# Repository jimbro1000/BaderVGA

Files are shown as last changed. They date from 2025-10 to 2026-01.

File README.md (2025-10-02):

# Terrible VGA #

Inspired by Ben Eater's discrete logic VGA and Leoneq's "bad vga" design,
this project implements a very basic, text only VGA display using just 1 
bit of a 128KB EEPROM data bus and 2KB of SRAM.

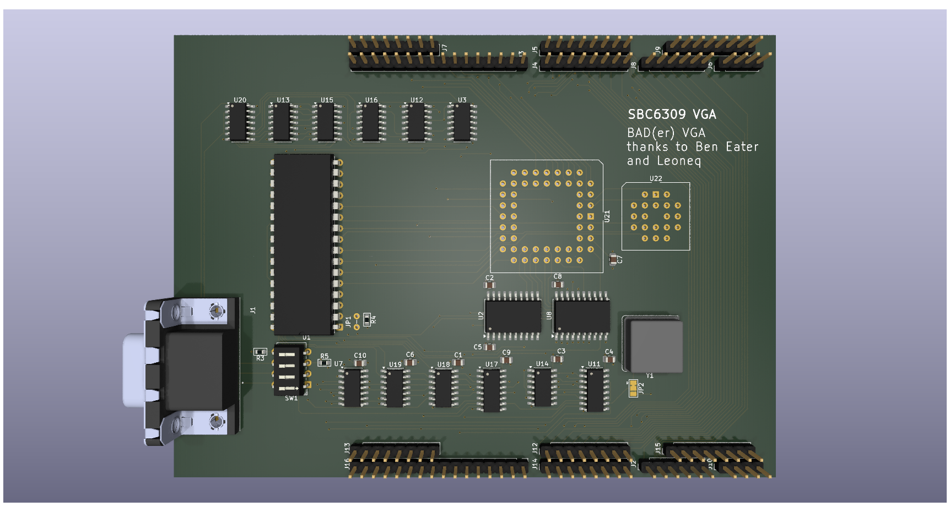
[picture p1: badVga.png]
Render of PCB


## Predictable issues ##

The logic chips used are clocked to near their limit (notably the 12-bit
counters) and struggle to meet the timing requirements of the design. 
Careful selection of components should help to resolve this.

The original designs by Ben and Leoneq were built on breadboard with no
practical ground plane and very little decoupling. This design is a 
dedicated 4-layer PCB with two solid ground planes that should help to 
resolve the problem. As much as possible, all signals are routed on a 
single layer with the "spare" layer used for power delivery.

Timing is not just an issue for the board's clock it is also a problem
for the host. The board clock is decoupled from the host which will,
inevitably, result in read and write conflicts. The host is expected to
be running at 3.147MHz while the video board is running at 20MHz. It
should be viable to gate host r/w operations such that they are blocked
(in the semaphore sense) by the video. If not the only option is to 
restrict write operations to the vertical blank period. The alternative
is to switch to a dual-port arrangement and bypass the problem completely.

## Integration ##
### Inputs ###

Integration with the host requires address bus, data bus, enable/select
and R/!W.

### Outputs ###

Outputs from the board, by default, are just the data bus but this needs
to be extended to include horizontal and vertical sync (TODO)

## Next ##

* Investigate dual-port ram option
* Investigate switch to 25.175MHz for better VGA compliance (can be
driven entirely from the host clock)
* Use latch and 3 bit load counter to reduce contention on databus
* Combine counter with 8 bit shift register (to reduce eeprom size
**and** allow eeprom programming on TL866 without adapters)
* Investigate combining with eeprom based state machine to manage
sync and blank timing

## References ##

Ben Eater VGA <https://eater.net/vga>

Leoneq <https://github.com/Leoneq/iNapGPU>

Dr Matt Regan VGA 
<https://github.com/Turing6502/ZX-Spectrum-No-ULA/blob/main/ZX%20Spectrum%20No%20ULA.pdf>

## License ##

This project is licensed under CC BY-SA 4.0
<https://creativecommons.org/licenses/by-sa/4.0/>

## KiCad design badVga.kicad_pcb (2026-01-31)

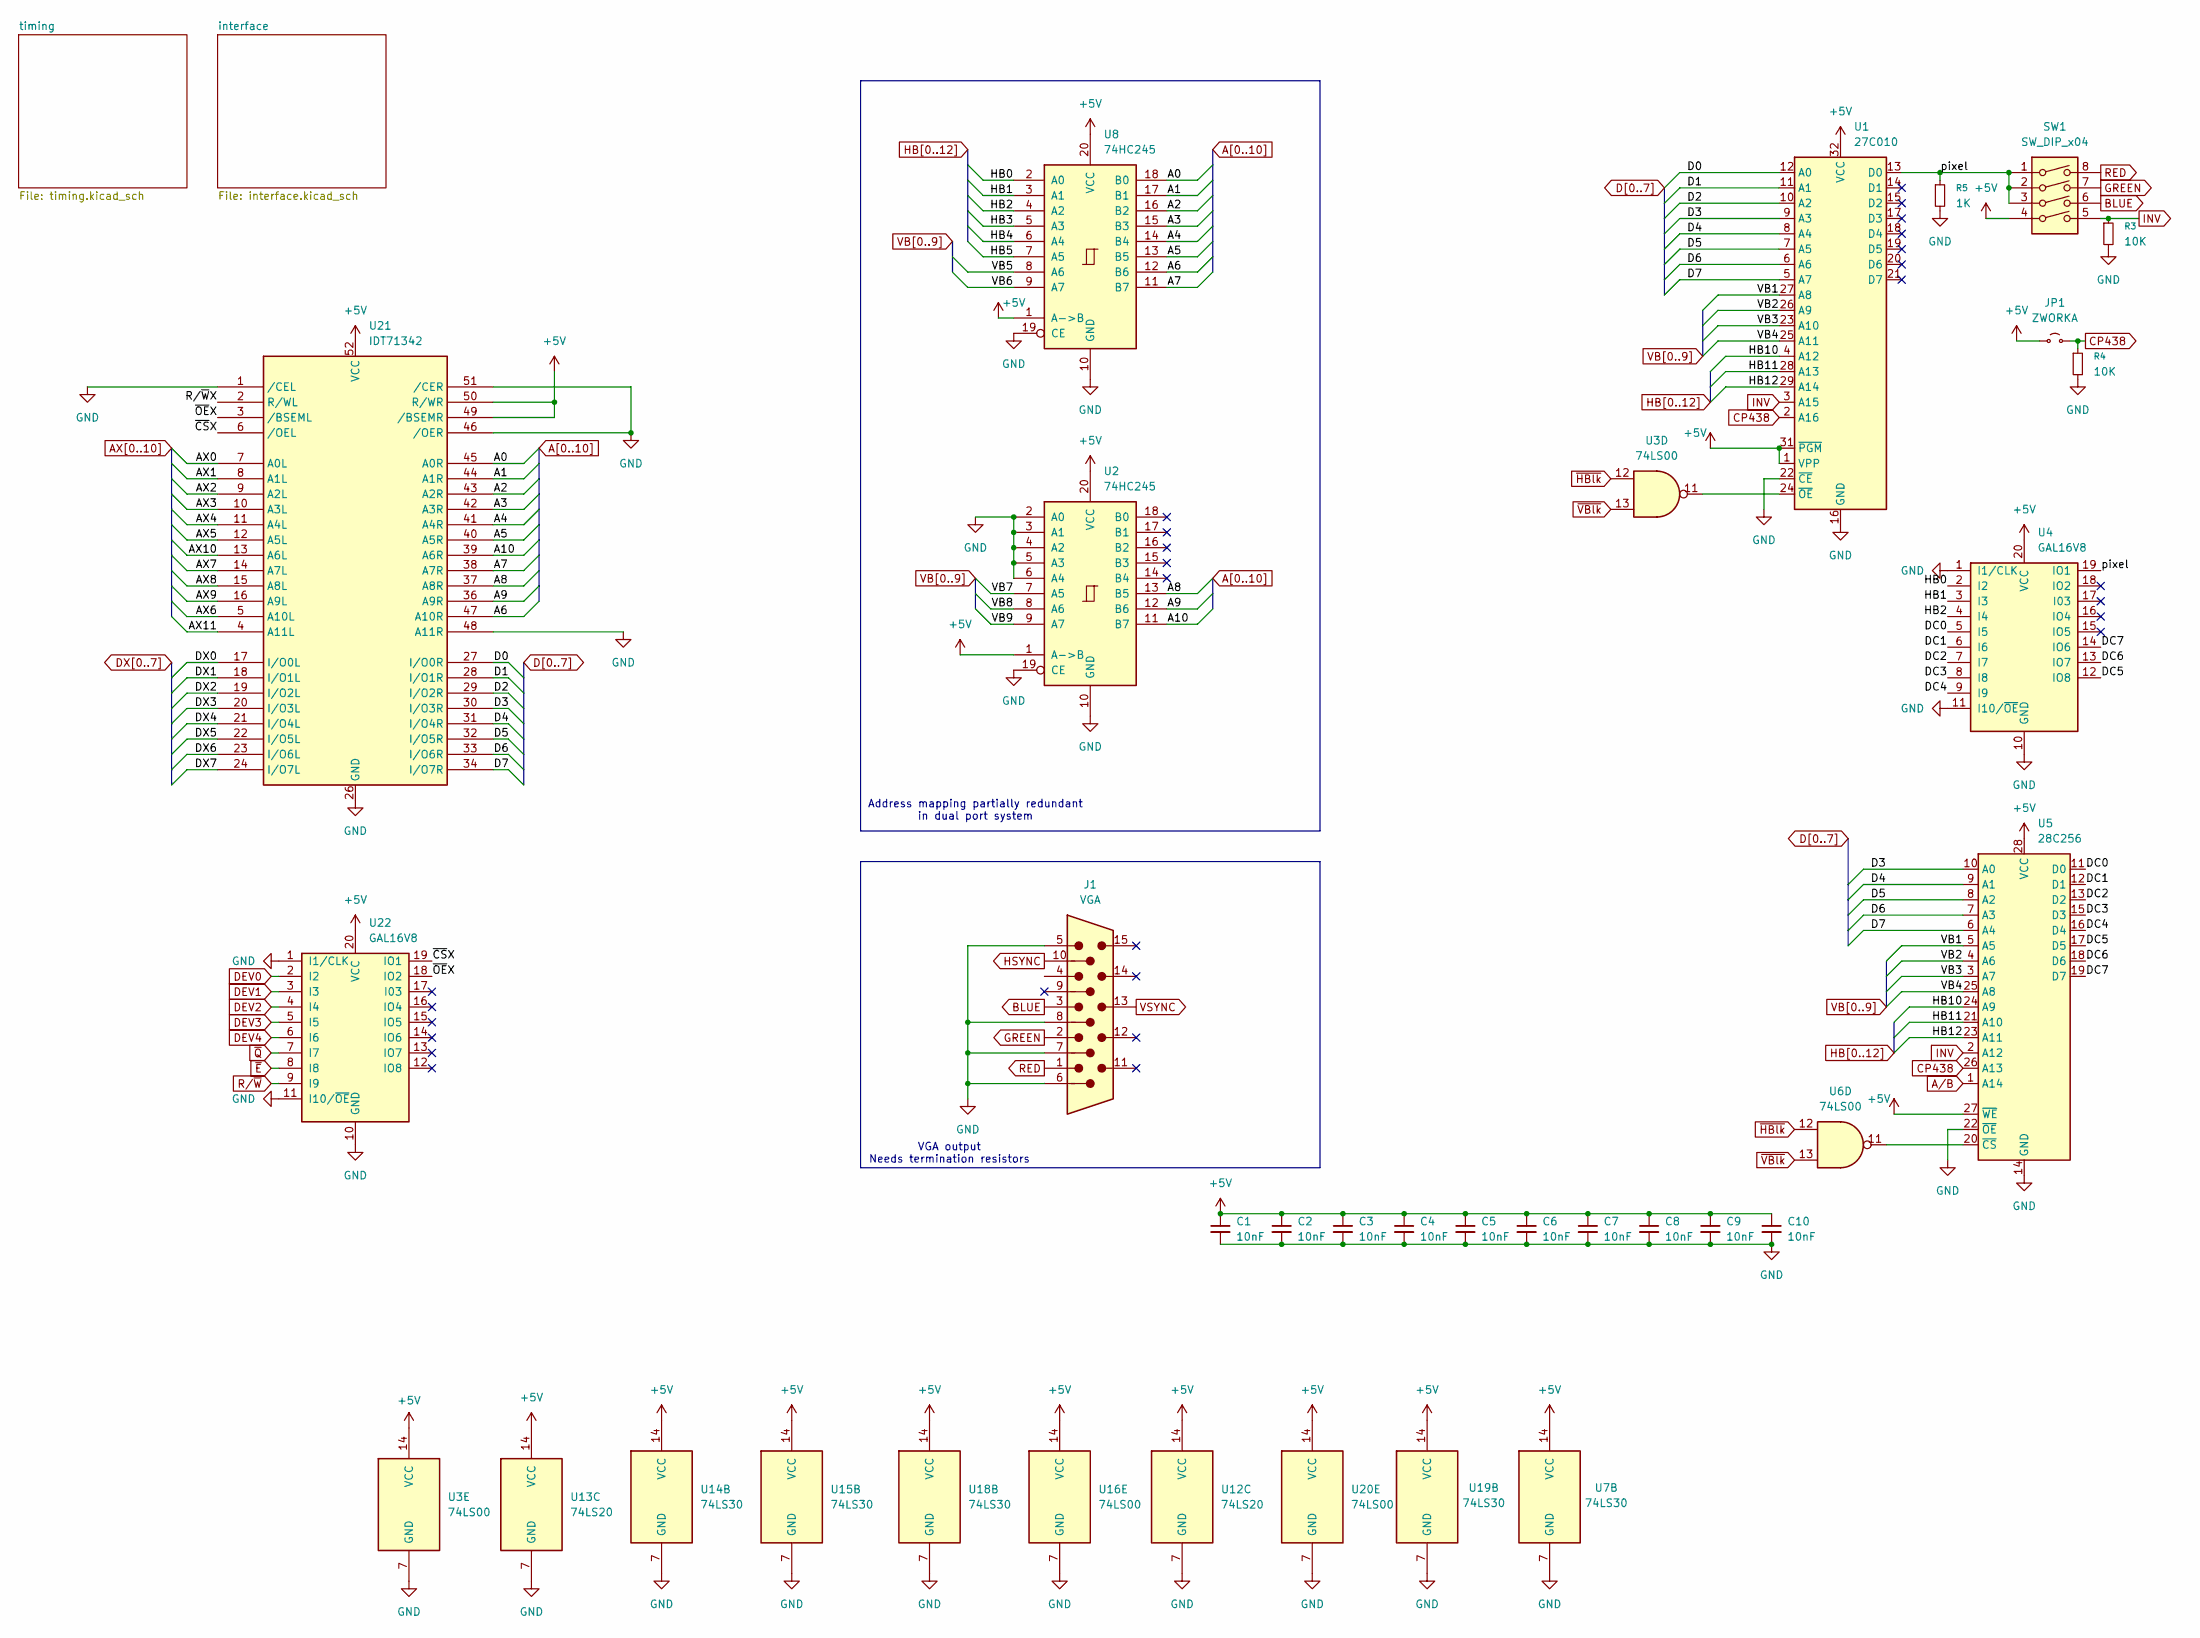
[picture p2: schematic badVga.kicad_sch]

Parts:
C1, C2, C3, C4, C5, C6, C7, C8, C9, C10: 10nF; C_0805_2012Metric; LCSC C1710
J1: VGA; AMPHENOL_ICD15S13E4GX00LF; DigiKey 609-5181-ND
JP1: ZWORKA; Jumper_P2.54mm_D0.7mm
R3, R4: 10K; R_0603_1608Metric; LCSC C25804
R5: 1K; R_0603_1608Metric; LCSC C21190
SW1: SW_DIP_x04; SW_DIP_SPSTx04_Slide_6.7x11.72mm_W7.62mm_P2.54mm_LowProfile
U1: 27C010; DIP-32_W15.24mm
U2, U8: 74HC245; SOIC-20W_7.5x12.8mm_P1.27mm; LCSC C2675537
U3, U6, U16, U20: 74LS00; SOIC-14_3.9x8.7mm_P1.27mm; LCSC C609793
U4, U22: GAL16V8; PLCC-20_THT-Socket
U5: 28C256
U7, U14, U15, U18, U19: 74LS30; SOIC-14_3.9x8.7mm_P1.27mm; LCSC C547583
U12, U13: 74LS20; SOIC-14_3.9x8.7mm_P1.27mm; LCSC C556253
U21: IDT71342; PLCC-52_THT-Socket

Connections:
+5V: C1.1, C2.1, C3.1, C4.1, C5.1, C6.1, C7.1, C8.1, C9.1, C10.1, JP1.1 (A), SW1.4, U1.1 (VPP), U1.31 (~PGM), U1.32 (VCC), U2.1 (A->B), U2.20 (VCC), U3.14 (VCC), U4.20 (VCC), U5.27 (~WE), U5.28 (VCC), U7.14 (VCC), U8.1 (A->B), U8.20 (VCC), U12.14 (VCC), U13.14 (VCC), U14.14 (VCC), U15.14 (VCC), U16.14 (VCC), U18.14 (VCC), U19.14 (VCC), U20.14 (VCC), U21.49 (/BSEMR), U21.50 (R/WR), U21.52 (VCC), U22.20 (VCC); also elsewhere on the board
/AX11: U21.4 (A11L)
/R/~WX: U21.2 (R/WL)
/pixel: R5.1, SW1.1, SW1.2, SW1.3, U1.13 (D0), U4.19 (IO1)
/~CSX: U21.6 (/OEL), U22.19 (IO1)
/~OEX: U21.3 (/BSEML), U22.18 (IO2)
A0: U8.18 (B0), U21.45 (A0R)
A1: U8.17 (B1), U21.44 (A1R)
A2: U8.16 (B2), U21.43 (A2R)
A3: U8.15 (B3), U21.42 (A3R)
A4: U8.14 (B4), U21.41 (A4R)
A5: U8.13 (B5), U21.40 (A5R)
A6: U8.12 (B6), U21.47 (A10R)
A7: U8.11 (B7), U21.38 (A7R)
A8: U2.13 (B5), U21.37 (A8R)
A9: U2.12 (B6), U21.36 (A9R)
A10: U2.11 (B7), U21.39 (A6R)
AX0: U21.7 (A0L); also elsewhere on the board
AX1: U21.8 (A1L); also elsewhere on the board
AX2: U21.9 (A2L); also elsewhere on the board
AX3: U21.10 (A3L); also elsewhere on the board
AX4: U21.11 (A4L); also elsewhere on the board
AX5: U21.12 (A5L); also elsewhere on the board
AX6: U21.5 (A10L); also elsewhere on the board
AX7: U21.14 (A7L); also elsewhere on the board
AX8: U21.15 (A8L); also elsewhere on the board
AX9: U21.16 (A9L); also elsewhere on the board
AX10: U21.13 (A6L); also elsewhere on the board
BLUE: J1.3, SW1.6
CP438: JP1.2 (B), R4.1, U1.2 (A16), U5.26 (A13)
D0: U1.12 (A0), U21.27 (I/O0R)
D1: U1.11 (A1), U21.28 (I/O1R)
D2: U1.10 (A2), U21.29 (I/O2R)
D3: U1.9 (A3), U5.10 (A0), U21.30 (I/O3R)
D4: U1.8 (A4), U5.9 (A1), U21.31 (I/O4R)
D5: U1.7 (A5), U5.8 (A2), U21.32 (I/O5R)
D6: U1.6 (A6), U5.7 (A3), U21.33 (I/O6R)
D7: U1.5 (A7), U5.6 (A4), U21.34 (I/O7R)
DEV0: U22.2 (I2); also elsewhere on the board
DEV1: U22.3 (I3); also elsewhere on the board
DEV2: U22.4 (I4); also elsewhere on the board
DEV3: U22.5 (I5); also elsewhere on the board
DEV4: U22.6 (I6); also elsewhere on the board
DX0: U21.17 (I/O0L); also elsewhere on the board
DX1: U21.18 (I/O1L); also elsewhere on the board
DX2: U21.19 (I/O2L); also elsewhere on the board
DX3: U21.20 (I/O3L); also elsewhere on the board
DX4: U21.21 (I/O4L); also elsewhere on the board
DX5: U21.22 (I/O5L); also elsewhere on the board
DX6: U21.23 (I/O6L); also elsewhere on the board
DX7: U21.24 (I/O7L); also elsewhere on the board
GND: C1.2, C2.2, C3.2, C4.2, C5.2, C6.2, C7.2, C8.2, C9.2, C10.2, J1.5, J1.6, J1.7, J1.8, R3.2, R4.2, R5.2, U1.16 (GND), U1.22 (~CE), U2.2 (A0), U2.3 (A1), U2.4 (A2), U2.5 (A3), U2.6 (A4), U2.10 (GND), U2.19 (CE), U3.7 (GND), U4.1 (I1/CLK), U4.10 (GND), U4.11 (I10/~OE), U5.14 (GND), U5.22 (~OE), U7.7 (GND), U8.10 (GND), U8.19 (CE), U12.7 (GND), U13.7 (GND), U14.7 (GND), U15.7 (GND), U16.7 (GND), U18.7 (GND), U19.7 (GND), U20.7 (GND), U21.1 (/CEL), U21.26 (GND), U21.46 (/OER), U21.48 (A11R), U21.51 (/CER), U22.1 (I1/CLK), U22.10 (GND), U22.11 (I10/~OE); also elsewhere on the board
GREEN: J1.2, SW1.7
HB0: U4.2 (I2), U8.2 (A0); also elsewhere on the board
HB1: U4.3 (I3), U8.3 (A1); also elsewhere on the board
HB2: U4.4 (I4), U8.4 (A2); also elsewhere on the board
HB3: U8.5 (A3); also elsewhere on the board
HB4: U8.6 (A4); also elsewhere on the board
HB5: U8.7 (A5); also elsewhere on the board
HB10: U1.4 (A12), U5.24 (A9); also elsewhere on the board
HB11: U1.28 (A13), U5.21 (A10); also elsewhere on the board
HB12: U1.29 (A14), U5.23 (A11); also elsewhere on the board
HSYNC: J1.10; also elsewhere on the board
INV: R3.1, SW1.5, U1.3 (A15), U5.2 (A12)
unnamed: U1.24 (~OE), U3.11
unnamed: U4.5 (I5), U5.11 (D0)
unnamed: U4.6 (I6), U5.12 (D1)
unnamed: U4.7 (I7), U5.13 (D2)
unnamed: U4.8 (I8), U5.15 (D3)
unnamed: U4.9 (I9), U5.16 (D4)
unnamed: U4.12 (IO8), U5.17 (D5)
unnamed: U4.13 (IO7), U5.18 (D6)
unnamed: U4.14 (IO6), U5.19 (D7)
unnamed: U5.20 (~CS), U6.11
RED: J1.1, SW1.8
R/~W: U22.9 (I9); also elsewhere on the board
VB1: U1.27 (A8), U5.5 (A5); also elsewhere on the board
VB2: U1.26 (A9), U5.4 (A6); also elsewhere on the board
VB3: U1.23 (A10), U5.3 (A7); also elsewhere on the board
VB4: U1.25 (A11), U5.25 (A8); also elsewhere on the board
VB5: U8.8 (A6); also elsewhere on the board
VB6: U8.9 (A7); also elsewhere on the board
VB7: U2.7 (A5); also elsewhere on the board
VB8: U2.8 (A6); also elsewhere on the board
VB9: U2.9 (A7); also elsewhere on the board
VSYNC: J1.13; also elsewhere on the board
~E: U22.8 (I8); also elsewhere on the board
~HBlk: U3.12, U6.12; also elsewhere on the board
~Q: U22.7 (I7); also elsewhere on the board
~VBlk: U3.13, U6.13; also elsewhere on the board

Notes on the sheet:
Address mapping partially redundant in dual port system
VGA output Needs termination resistors

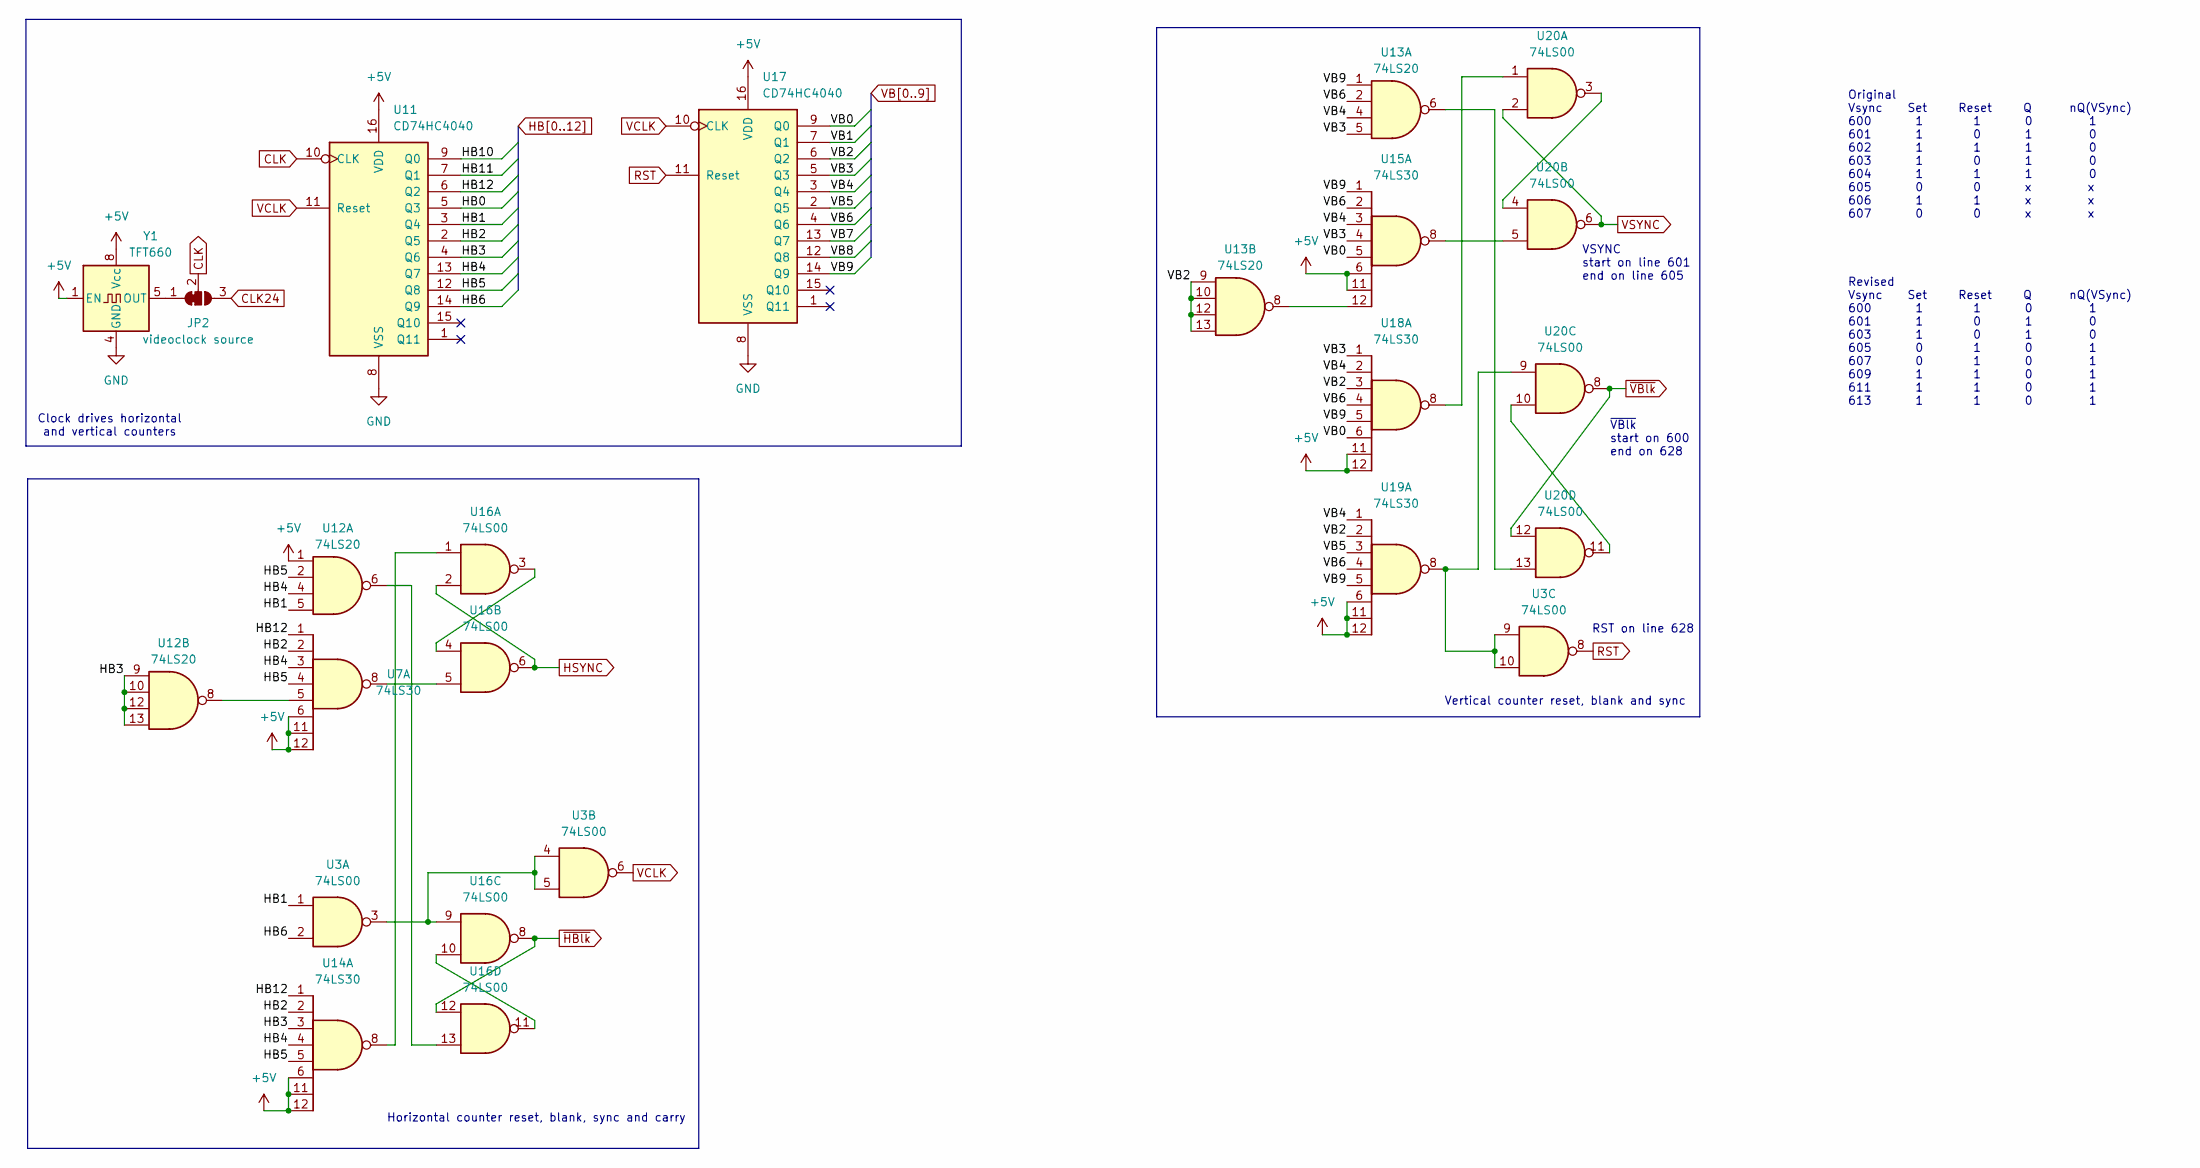
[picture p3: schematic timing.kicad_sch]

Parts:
JP2: videoclock source; SolderJumper-3_P1.3mm_Bridged12_Pad1.0x1.5mm
U3, U16, U20: 74LS00; SOIC-14_3.9x8.7mm_P1.27mm; LCSC C609793
U7, U14, U15, U18, U19: 74LS30; SOIC-14_3.9x8.7mm_P1.27mm; LCSC C547583
U11, U17: CD74HC4040; SOIC-16_3.9x9.9mm_P1.27mm; LCSC C2865249
U12, U13: 74LS20; SOIC-14_3.9x8.7mm_P1.27mm; LCSC C556253
Y1: TFT660; Oscillator_DIP-8

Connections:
+5V: U7.6, U7.11, U7.12, U11.16 (VDD), U12.1, U14.6, U14.11, U14.12, U15.6, U15.11, U17.16 (VDD), U18.11, U18.12, U19.6, U19.11, U19.12, Y1.1 (EN), Y1.8 (Vcc); also elsewhere on the board
CLK: JP2.2 (C), U11.10 (CLK)
CLK24: JP2.3 (B); also elsewhere on the board
GND: U11.8 (VSS), U17.8 (VSS), Y1.4 (GND); also elsewhere on the board
HB0: U11.5 (Q3); also elsewhere on the board
HB1: U3.1, U11.3 (Q4), U12.5; also elsewhere on the board
HB2: U7.2, U11.2 (Q5), U14.2; also elsewhere on the board
HB3: U11.4 (Q6), U12.9, U12.10, U12.12, U12.13, U14.3; also elsewhere on the board
HB4: U7.3, U11.13 (Q7), U12.4, U14.4; also elsewhere on the board
HB5: U7.4, U11.12 (Q8), U12.2, U14.5; also elsewhere on the board
HB6: U3.2, U11.14 (Q9)
HB10: U11.9 (Q0); also elsewhere on the board
HB11: U11.7 (Q1); also elsewhere on the board
HB12: U7.1, U11.6 (Q2), U14.1; also elsewhere on the board
HSYNC: U16.2, U16.6; also elsewhere on the board
unnamed: JP2.1 (A), Y1.5 (OUT)
unnamed: U12.6, U16.13
unnamed: U7.5, U12.8
unnamed: U13.6, U20.13
unnamed: U13.8, U15.12
unnamed: U14.8, U16.1
unnamed: U15.8, U20.5
unnamed: U16.3, U16.4
unnamed: U7.8, U16.5
unnamed: U3.3, U3.4, U3.5, U16.9
unnamed: U16.10, U16.11
unnamed: U18.8, U20.1
unnamed: U3.9, U3.10, U19.8, U20.9
unnamed: U20.3, U20.4
unnamed: U20.10, U20.11
RST: U3.8, U17.11 (Reset)
VB0: U15.5, U17.9 (Q0), U18.6
VB1: U17.7 (Q1); also elsewhere on the board
VB2: U13.9, U13.10, U13.12, U13.13, U17.6 (Q2), U18.3, U19.2; also elsewhere on the board
VB3: U13.5, U15.4, U17.5 (Q3), U18.1; also elsewhere on the board
VB4: U13.4, U15.3, U17.3 (Q4), U18.2, U19.1; also elsewhere on the board
VB5: U17.2 (Q5), U19.3; also elsewhere on the board
VB6: U13.2, U15.2, U17.4 (Q6), U18.4, U19.4; also elsewhere on the board
VB7: U17.13 (Q7); also elsewhere on the board
VB8: U17.12 (Q8); also elsewhere on the board
VB9: U13.1, U15.1, U17.14 (Q9), U18.5, U19.5; also elsewhere on the board
VCLK: U3.6, U11.11 (Reset), U17.10 (CLK)
VSYNC: U20.2, U20.6; also elsewhere on the board
~HBlk: U16.8, U16.12; also elsewhere on the board
~VBlk: U20.8, U20.12; also elsewhere on the board

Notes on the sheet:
RST on line 628
Original Vsync Set Reset Q nQ(VSync) 600 1 1 0 1 601 1 0 1 0 602 1 1 1 0 603 1 0 1 0 604 1 1 1 0 605 0 0 x x 606 1 1 x x 607 0 0 x x
~{VBlk} start on 600 end on 628
Vertical counter reset, blank and sync
Revised Vsync Set Reset Q nQ(VSync) 600 1 1 0 1 601 1 0 1 0 603 1 0 1 0 605 0 1 0 1 607 0 1 0 1 609 1 1 0 1 611 1 1 0 1 613 1 1 0 1
Clock drives horizontal and vertical counters
VSYNC start on line 601 end on line 605
Horizontal counter reset, blank, sync and carry

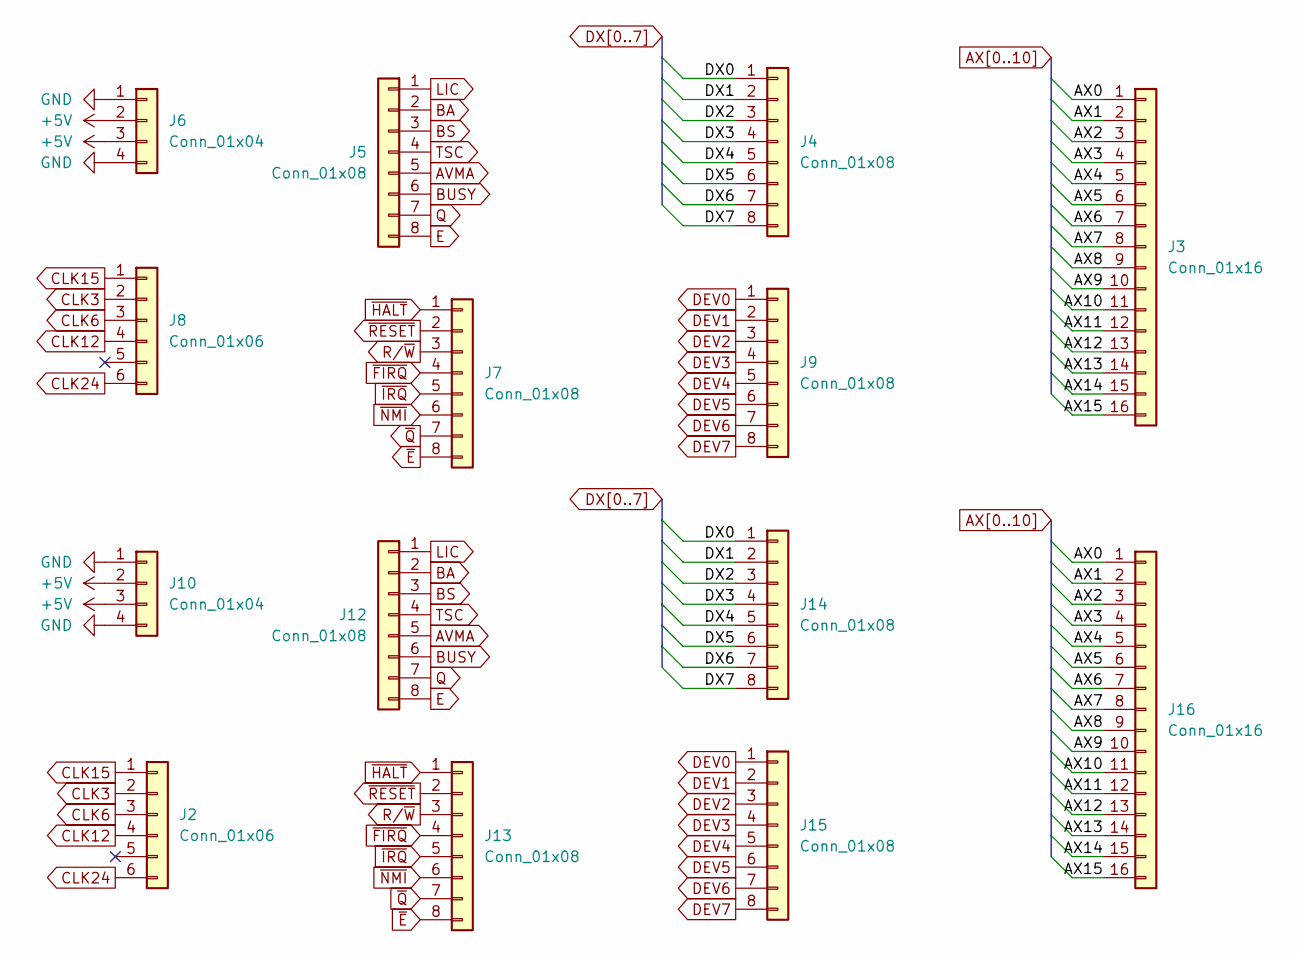
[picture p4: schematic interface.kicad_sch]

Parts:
J2, J8: Conn_01x06; PinHeader_1x06_P2.54mm_Vertical
J3, J16: Conn_01x16; PinHeader_1x16_P2.54mm_Vertical
J4, J5, J7, J9, J12, J13, J14, J15: Conn_01x08; PinHeader_1x08_P2.54mm_Vertical
J6, J10: Conn_01x04; PinHeader_1x04_P2.54mm_Vertical

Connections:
+5V: J6.2, J6.3, J10.2, J10.3; also elsewhere on the board
/interface/AX11: J3.12, J16.12
/interface/AX12: J3.13, J16.13
/interface/AX13: J3.14, J16.14
/interface/AX14: J3.15, J16.15
/interface/AX15: J3.16, J16.16
AVMA: J5.5, J12.5
AX0: J3.1, J16.1; also elsewhere on the board
AX1: J3.2, J16.2; also elsewhere on the board
AX2: J3.3, J16.3; also elsewhere on the board
AX3: J3.4, J16.4; also elsewhere on the board
AX4: J3.5, J16.5; also elsewhere on the board
AX5: J3.6, J16.6; also elsewhere on the board
AX6: J3.7, J16.7; also elsewhere on the board
AX7: J3.8, J16.8; also elsewhere on the board
AX8: J3.9, J16.9; also elsewhere on the board
AX9: J3.10, J16.10; also elsewhere on the board
AX10: J3.11, J16.11; also elsewhere on the board
BA: J5.2, J12.2
BS: J5.3, J12.3
BUSY: J5.6, J12.6
CLK3: J2.2, J8.2
CLK6: J2.3, J8.3
CLK12: J2.4, J8.4
CLK15: J2.1, J8.1
CLK24: J2.6, J8.6; also elsewhere on the board
DEV0: J9.1, J15.1; also elsewhere on the board
DEV1: J9.2, J15.2; also elsewhere on the board
DEV2: J9.3, J15.3; also elsewhere on the board
DEV3: J9.4, J15.4; also elsewhere on the board
DEV4: J9.5, J15.5; also elsewhere on the board
DEV5: J9.6, J15.6
DEV6: J9.7, J15.7
DEV7: J9.8, J15.8
DX0: J4.1, J14.1; also elsewhere on the board
DX1: J4.2, J14.2; also elsewhere on the board
DX2: J4.3, J14.3; also elsewhere on the board
DX3: J4.4, J14.4; also elsewhere on the board
DX4: J4.5, J14.5; also elsewhere on the board
DX5: J4.6, J14.6; also elsewhere on the board
DX6: J4.7, J14.7; also elsewhere on the board
DX7: J4.8, J14.8; also elsewhere on the board
E: J5.8, J12.8
GND: J6.1, J6.4, J10.1, J10.4; also elsewhere on the board
LIC: J5.1, J12.1
Q: J5.7, J12.7
R/~W: J7.3, J13.3; also elsewhere on the board
TSC: J5.4, J12.4
~E: J7.8, J13.8; also elsewhere on the board
~FIRQ: J7.4, J13.4
~HALT: J7.1, J13.1
~IRQ: J7.5, J13.5
~NMI: J7.6, J13.6
~Q: J7.7, J13.7; also elsewhere on the board
~RESET: J7.2, J13.2

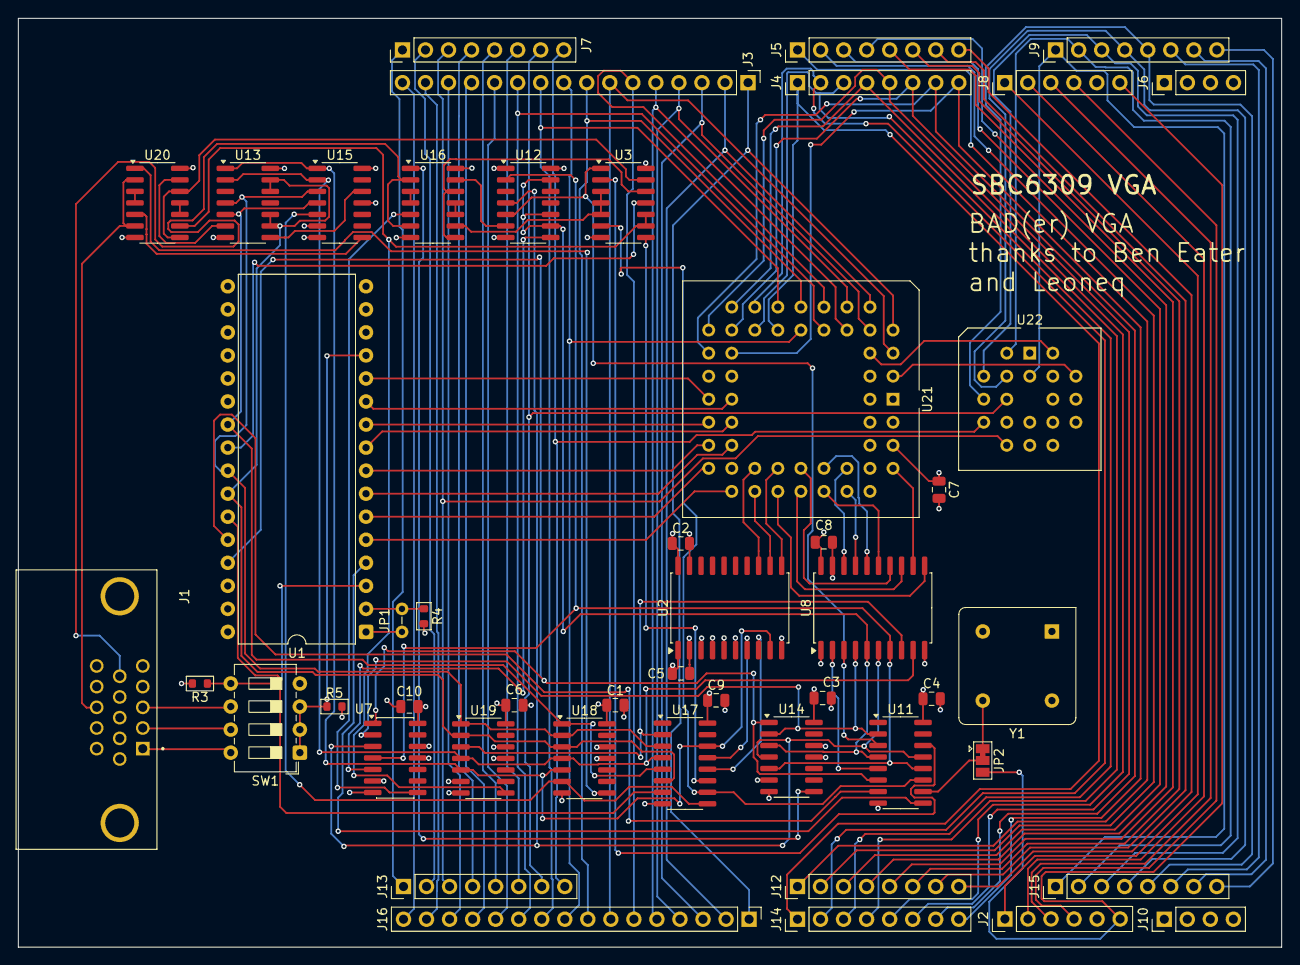
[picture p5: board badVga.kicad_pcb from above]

Board: 4 copper layers, 139.3 x 102.4 mm, 49 parts (0 on the bottom side), 125 nets.

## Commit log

2025-11-22 adjust to sbc6309 io
    [badVga.kicad_pcb, badVga.kicad_sch, interface.kicad_sch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]
2026-01-31 fix sync signal generation
    [badVga.kicad_pcb, badVga.kicad_sch, interface.kicad_sch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]
